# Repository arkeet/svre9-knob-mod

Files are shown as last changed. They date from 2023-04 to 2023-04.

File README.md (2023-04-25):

SVRE9 knob bearing upgrade
==========================

This modifies the knob assembly from a SVRE9 controller to use ball bearings,
similar to Valkyrie Model. It reuses the original shaft, torque limiter, and
encoder bracket.

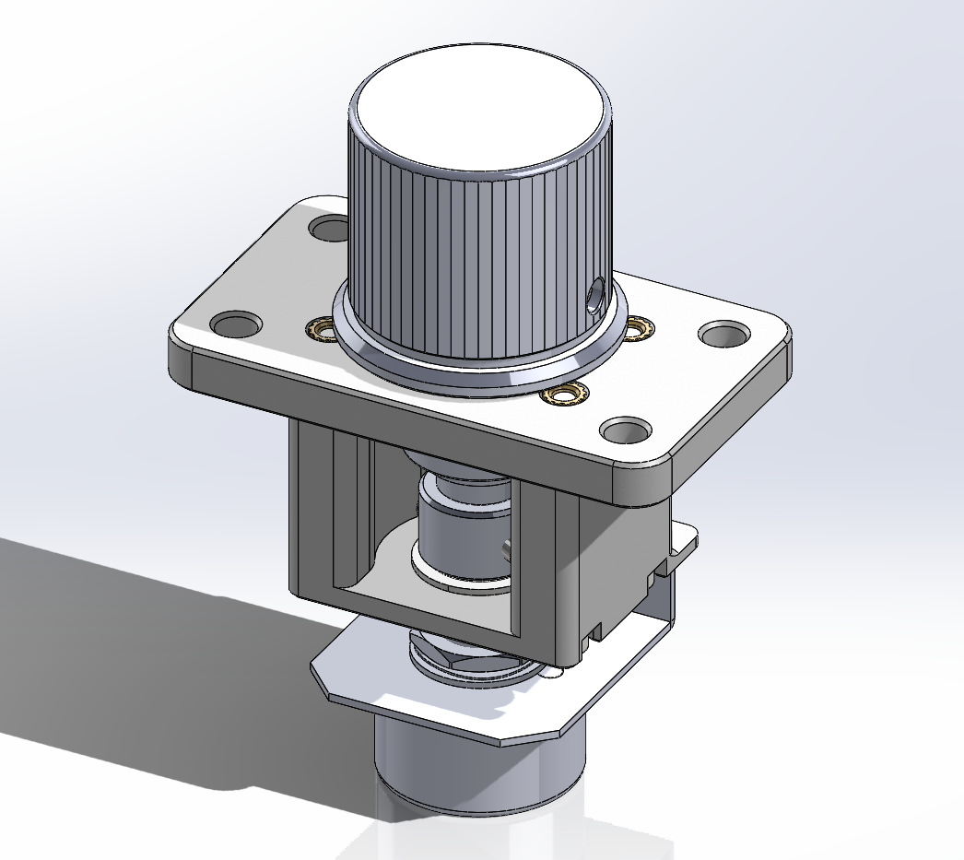
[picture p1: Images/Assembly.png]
Assembly


Bill of materials
-----------------

- M3x30 socket head cap screw - 4x
- M3 hex nut, or M3x5x4 (Voron) threaded insert - 4x
- 6x10x3mm flanged bearing (MF106-ZZ or MF106-2RS)
- 8x14x4mm flanged bearing (MF148-ZZ or MF148-2RS)

Print settings
--------------

0.2mm layer height, 4 perimeters, 5 top/bottom solid layers, 40% infill.

Tested with ABS but probably anything is fine.

Assembly
--------

Required tools: 1.5mm, 2mm, and 2.5mm hex drivers

First, disassemble the original knob assembly, but keep the encoder mounted on
the bracket. Before assembling, check that the bearings fit over the shaft
without excessive force. You may need to sand down the shaft slightly to make
it fit.

1. Install the 4 hex nuts or threaded inserts into the top plate.
   Snap the bearings into the printed parts from the top side.
2. Slide the torque limiter onto the shaft, and the shaft into the top plate,
   fitting the torque limiter tabs into the top plate slot.
3. Put the spacer on the shaft, flat face up.
4. Put the knob on the shaft, pressing the whole stack together firmly to
   ensure the bearing and spacer are seated. Secure it with the set screws.
5. Use 4 M3x30 screws to attach the bottom part to the top plate.
6. Install the encoder with its bracket, and secure it with the set screws.

[Step by step images](Assembly_images.md)

Disclaimer
----------

Copyright 2023 Adrian Keet.

This source describes Open Hardware and is licensed under the CERN-OHL-W v2.

You may redistribute and modify this source and make products using it under
the terms of the CERN-OHL-W v2 (https://cern.ch/cern-ohl). This source is
distributed WITHOUT ANY EXPRESS OR IMPLIED WARRANTY, INCLUDING OF
MERCHANTABILITY, SATISFACTORY QUALITY AND FITNESS FOR A PARTICULAR PURPOSE.
Please see the CERN-OHL-W v2 for applicable conditions.

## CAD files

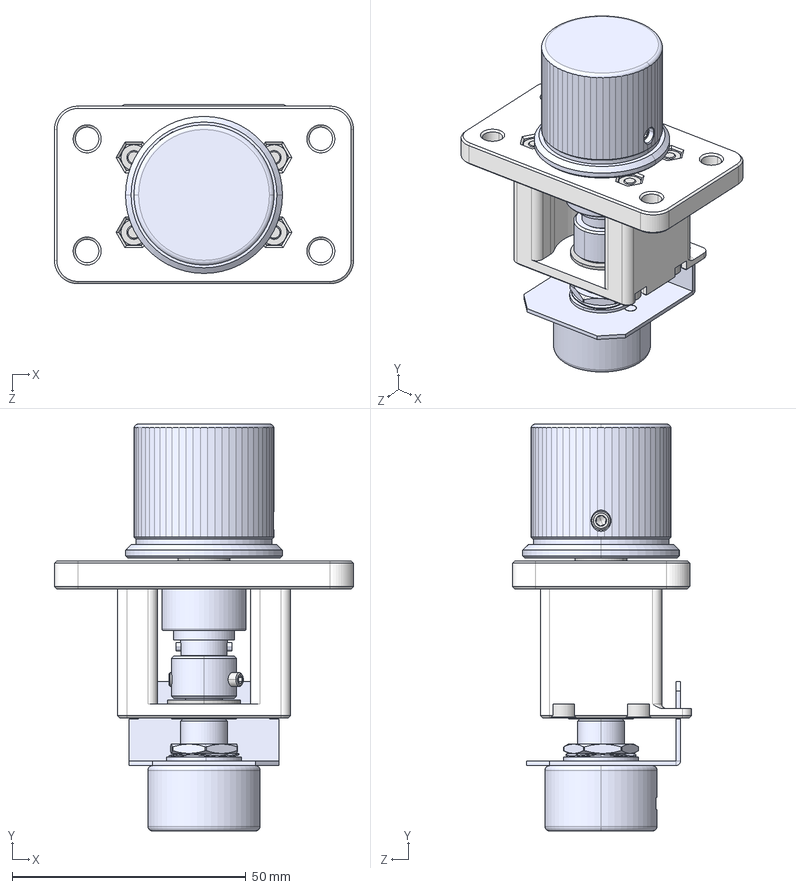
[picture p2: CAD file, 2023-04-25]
CAD/SVRE9 knob assembly mod (Hex nut).STEP
64.0 x 87.1 x 38.4 mm
Top plate^SVRE9 knob assembly mod_Hex nut
HNT2-ST-M3_HNT2-ST-M3 x 4
FL676ZZ
Spacer top^SVRE9 knob assembly mod
Shaft^SVRE9 knob assembly mod
Body^TLE1-618-5W_SVRE9 knob assembly mod
Shaft^TLE1-618-5W_SVRE9 knob assembly mod
SSHC-ST-M3-6_SSHC-ST-M3-6 x 2
Base^SVRE9 knob assembly mod
CSH-STN-M3-30_CSH-STN-M3-30 x 4
MF148ZZ
Encoder bracket^SVRE9 knob assembly mod
Body^ELV-24
Shaft^ELV-24
Wave washer 41010^ELV-24
Flat washer^ELV-24
Nut^ELV-24
Knob^SVRE9 knob assembly mod
SSHC-ST-M4-12_SSHC-ST-M4-12 x 2

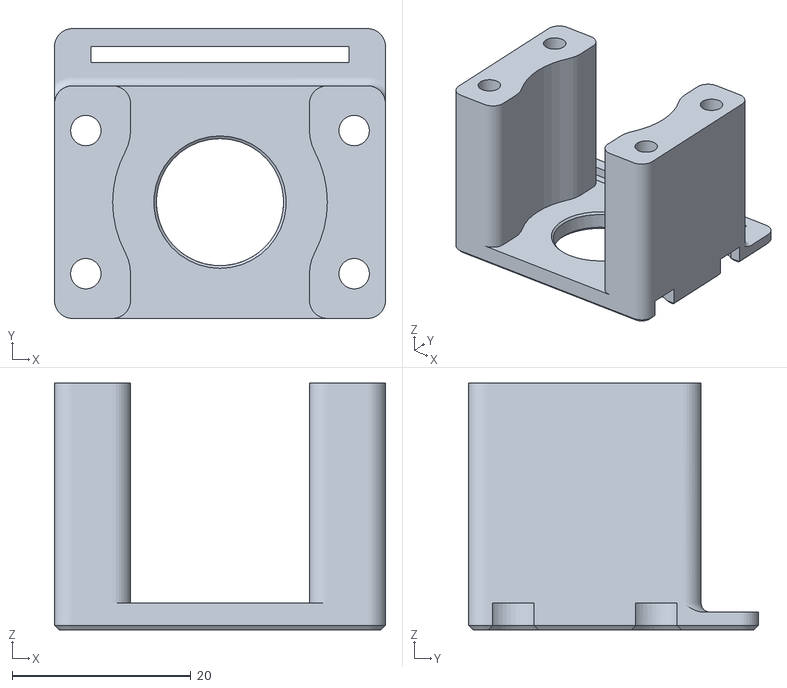
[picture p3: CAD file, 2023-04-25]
STL/Base.STL
37.0 x 32.4 x 27.6

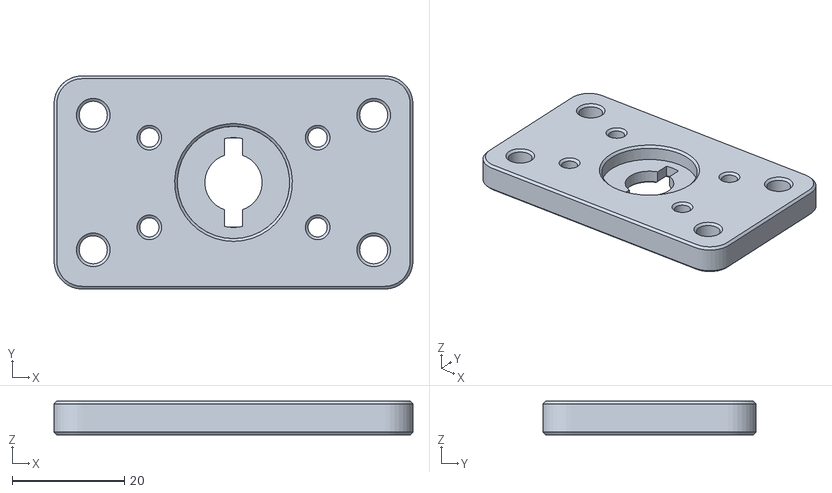
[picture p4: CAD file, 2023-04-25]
STL/Top plate (Hex nut).STL
64.0 x 38.0 x 6.00

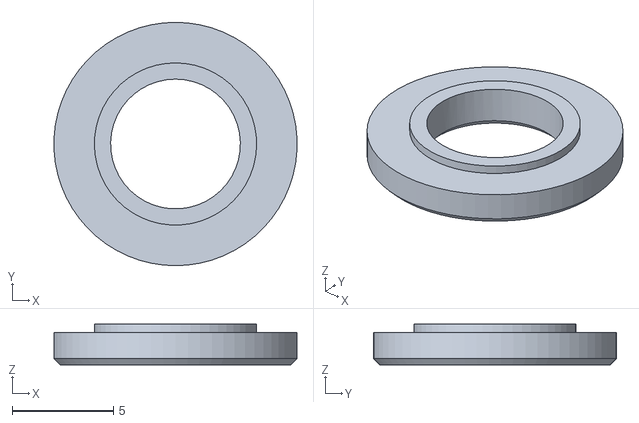
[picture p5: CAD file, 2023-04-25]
STL/Spacer top.STL
12.0 x 12.0 x 2.00

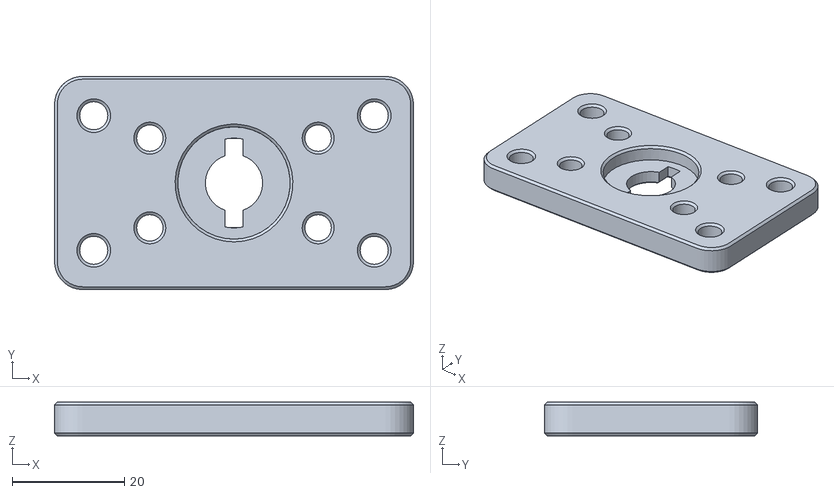
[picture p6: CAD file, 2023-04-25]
STL/Top plate (Threaded insert).STL
64.0 x 38.0 x 6.00

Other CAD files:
CAD/SVRE9 knob assembly mod (Threaded insert).STEP

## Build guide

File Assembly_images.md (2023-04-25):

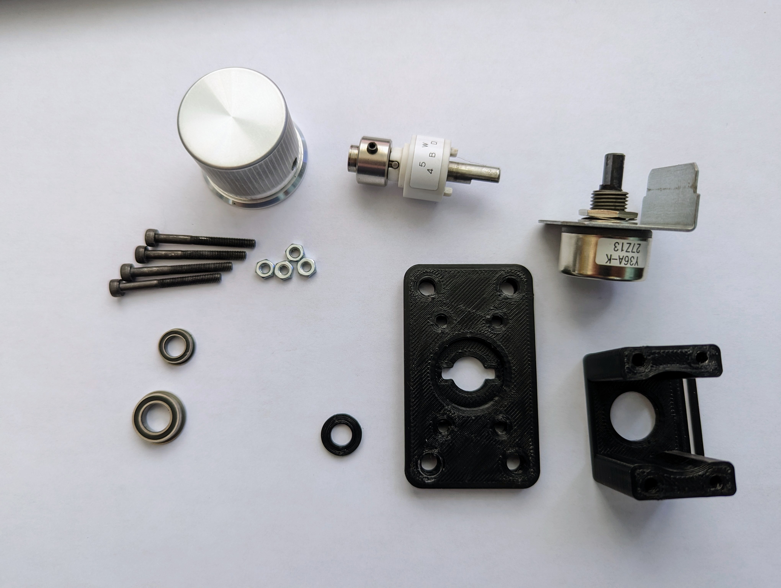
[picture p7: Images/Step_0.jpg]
Step 0


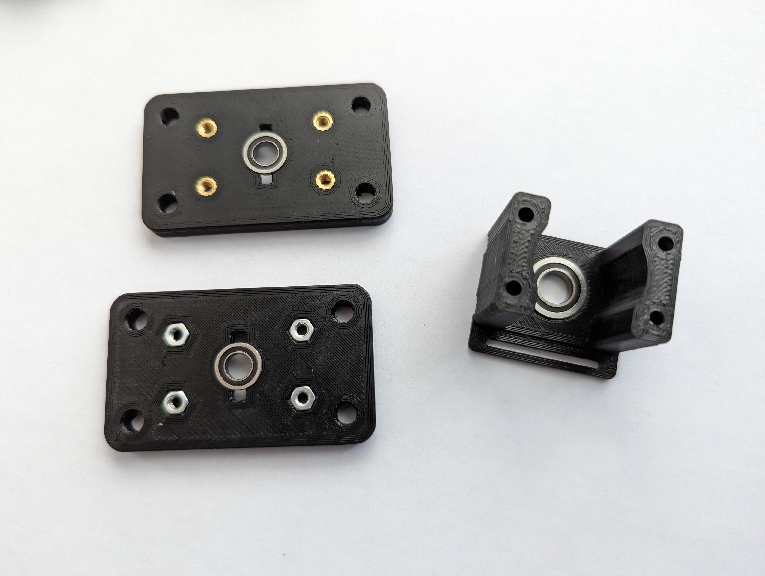
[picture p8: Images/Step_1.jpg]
Step 1


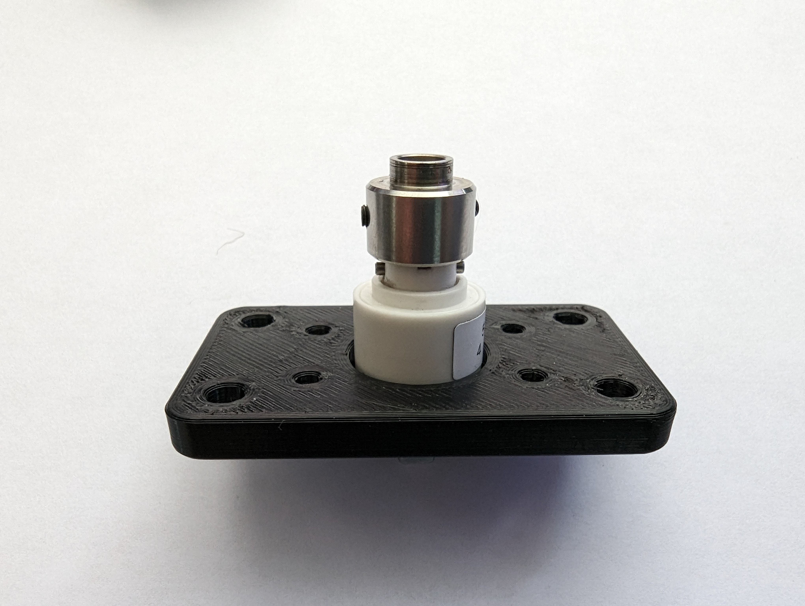
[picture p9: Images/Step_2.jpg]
Step 2


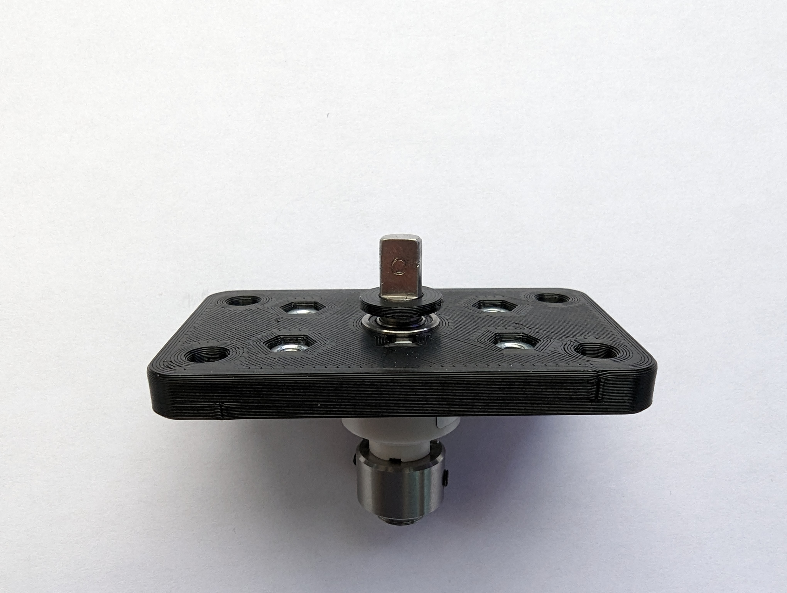
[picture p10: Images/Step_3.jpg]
Step 3


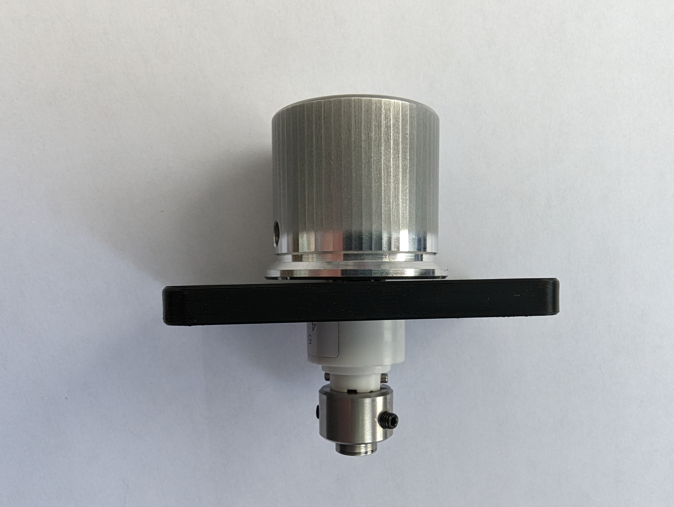
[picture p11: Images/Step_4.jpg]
Step 4


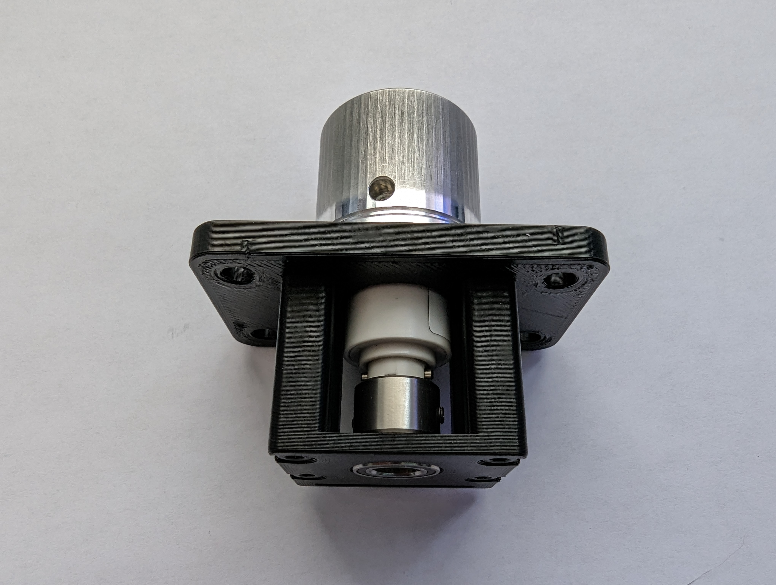
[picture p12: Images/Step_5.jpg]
Step 5


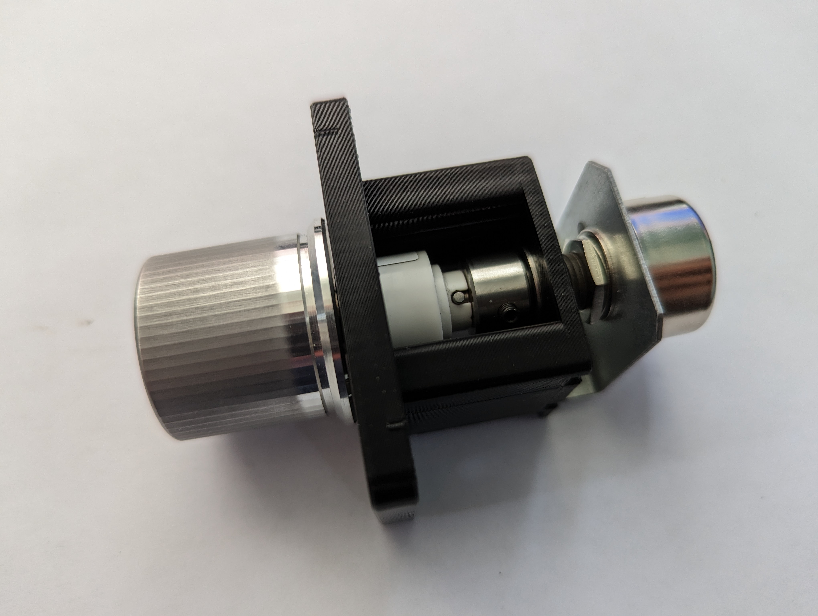
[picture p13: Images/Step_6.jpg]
Step 6


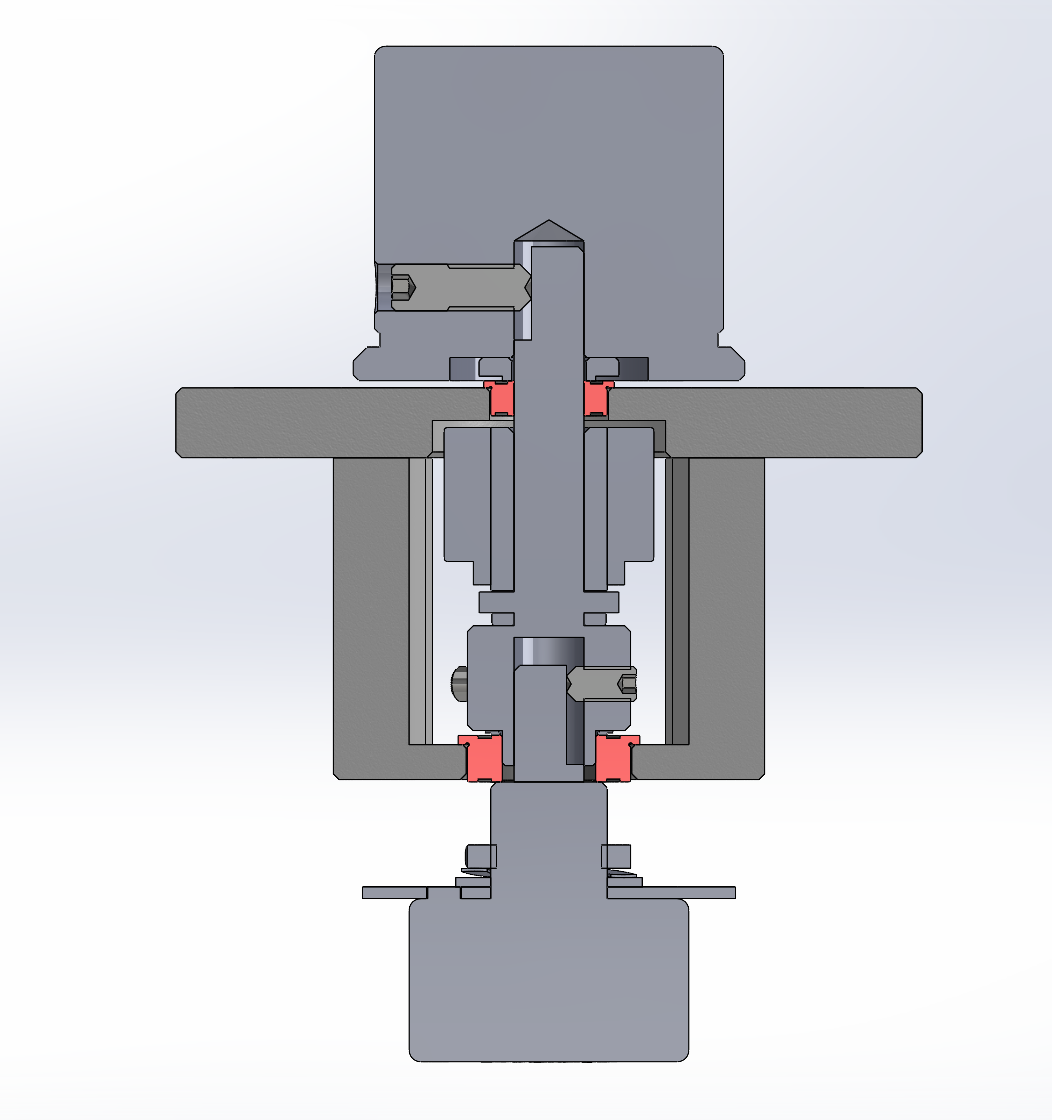
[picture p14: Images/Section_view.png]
Section view


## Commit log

2023-04-25 Initial release
    [Base.STL, SVRE9 knob assembly mod (Hex nut).STEP, SVRE9 knob assembly mod (Threaded insert).STEP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]
2023-04-25 Add print settings
